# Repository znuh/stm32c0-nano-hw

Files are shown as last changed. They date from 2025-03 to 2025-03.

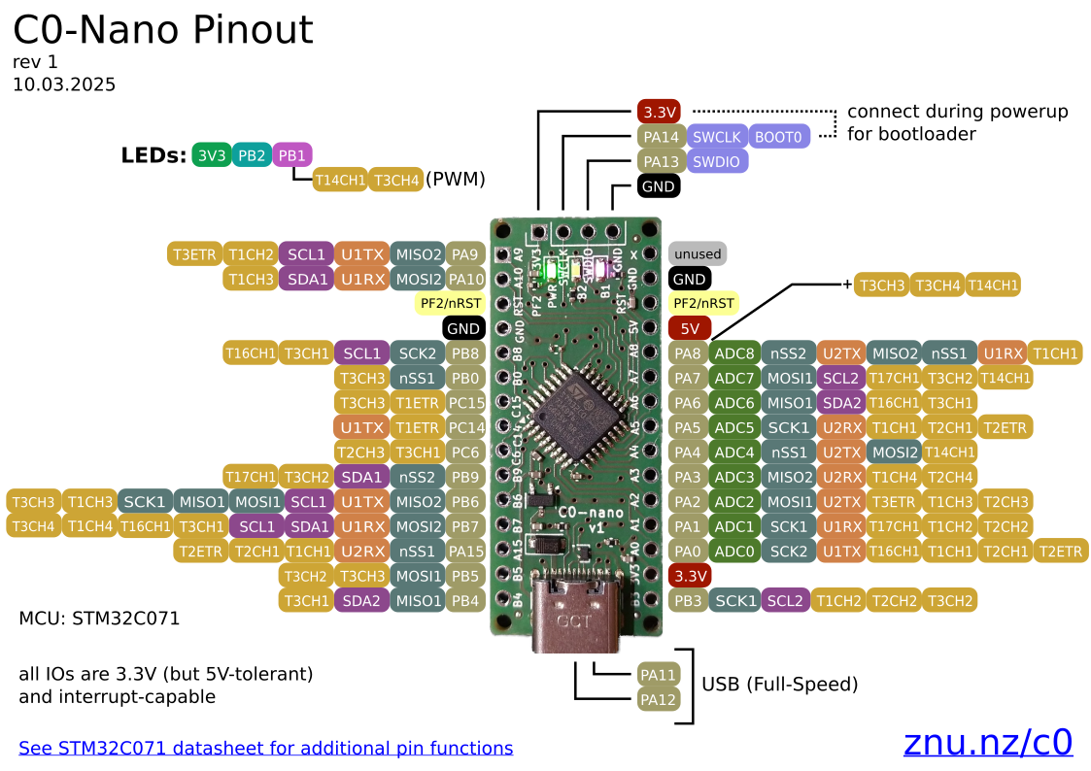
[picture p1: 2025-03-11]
pinouts/pinout.png

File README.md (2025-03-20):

# STM32C0-Nano Hardware Design Files
This is a very simple and cheap STM32C071 board.  

It is largely compatible to ATMega-based "Nano" boards - with 3.3V IOs:  


# Features
* Simple, very low cost (2L, all parts on top of PCB)
* Builtin USB (DFU) bootloader
* Full-speed USB, no crystal needed
(using the Clock Recovery System (CRS))
* 48MHz ARM® Cortex®-M0+ with 24KB SRAM and 128KB Flash memory
* 23+2 GPIOs with 2x SPIs, 2x UARTs, 2x I2C and lots of timer channels
* 9 analog input channels, internal voltage reference
* Fast 2.5MSps 12-bit Analog-to-digital converter (ADC)
* 2x user LEDs (not shared with other GPIOs)

# More Details
see <a href="https://znu.nz/c0">znu.nz/c0</a>

# Demo Firmware
* <a href="https://github.com/znuh/stm32-ACMtest">USB ACM Console + Blinkenlights</a>

# Note
If you build this yourself, you must set the **NBOOT_SEL** Bit in the Flash Option Bytes to **zero** (e.g. via SWD), or you cannot use **BOOT0** to invoke the bootloader during powerup.

# License
Designed by Benedikt Heinz &lt;hunz at mailbox.org&gt;

Creative Commons Attribution/Share-Alike, all text above must be included in any redistribution. See license.txt for additional details.

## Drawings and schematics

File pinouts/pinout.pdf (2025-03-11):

### connect during powerup for bootloader

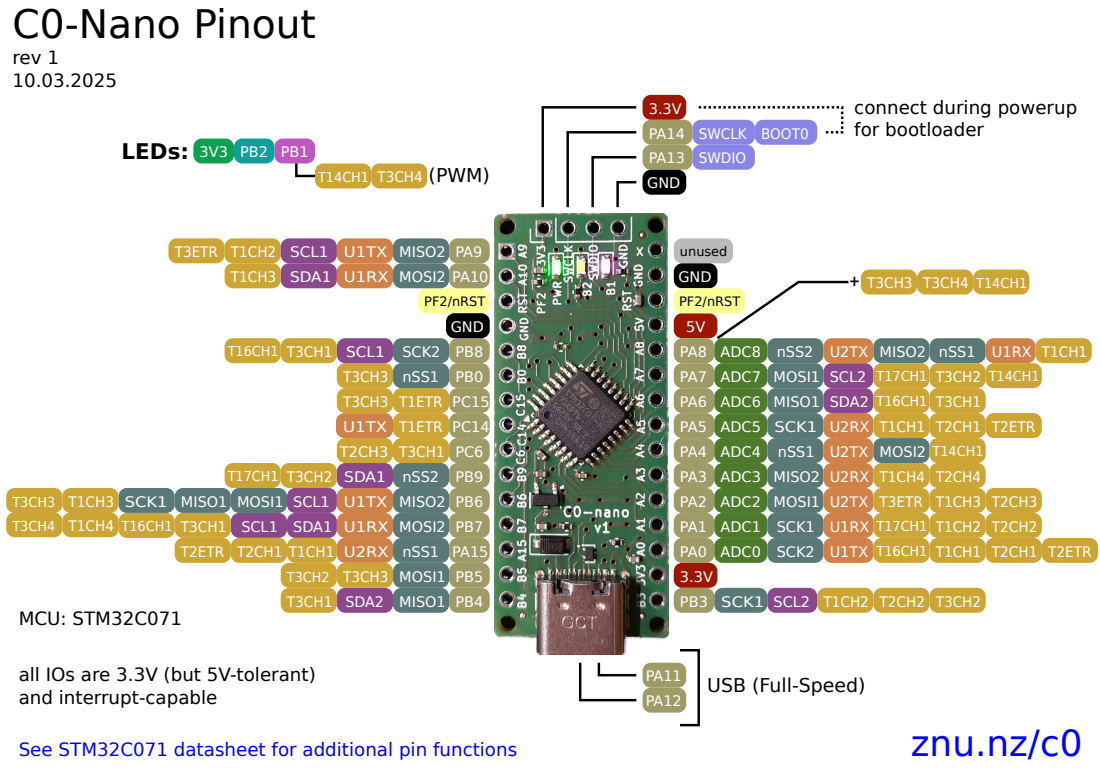
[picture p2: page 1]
GND; PF2/nRST; ADC8 ADC7 ADC6 ADC5 ADC4 ADC3 ADC2 ADC1 ADC0; MISO1; MOSI2; MOSI1; nSS1; SCK2; SCK1; MOSI1 U2TX; MISO2 U2RX; nSS1 U2TX MOSI2; MISO1 SDA2; MOSI1 SCL2; nSS2 U2TX MISO2 nSS1 U1RX; SDA2; U1TX SCL1 SDA1 U1RX; SCK1 MISO1 MOSI1 SCL1; MISO2; SDA1 nSS2; U1TX T1ETR; T3CH3 T1ETR; T3CH3 nSS1; T16CH1 T3CH1 SCL1 SCK2; T1CH2 SCL1; SDA1; T3ETR; T2ETR T2CH1 T1CH1; SCL2 T1CH2 T2CH2 T3CH2; U1TX T16CH1 T1CH1 T2CH1 T2ETR; T3ETR T1CH3 T2CH3; T1CH1 T2CH1 T2ETR; 3.3V PA14 PA13 GND; SWCLK SWDIO; BOOT0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

all IOs are 3.3V (but 5V-tolerant)
and interrupt-capable

See STM32C071 datasheet for additional pin functions (https://www.st.com/resource/en/datasheet/stm32c071kb.pdf)

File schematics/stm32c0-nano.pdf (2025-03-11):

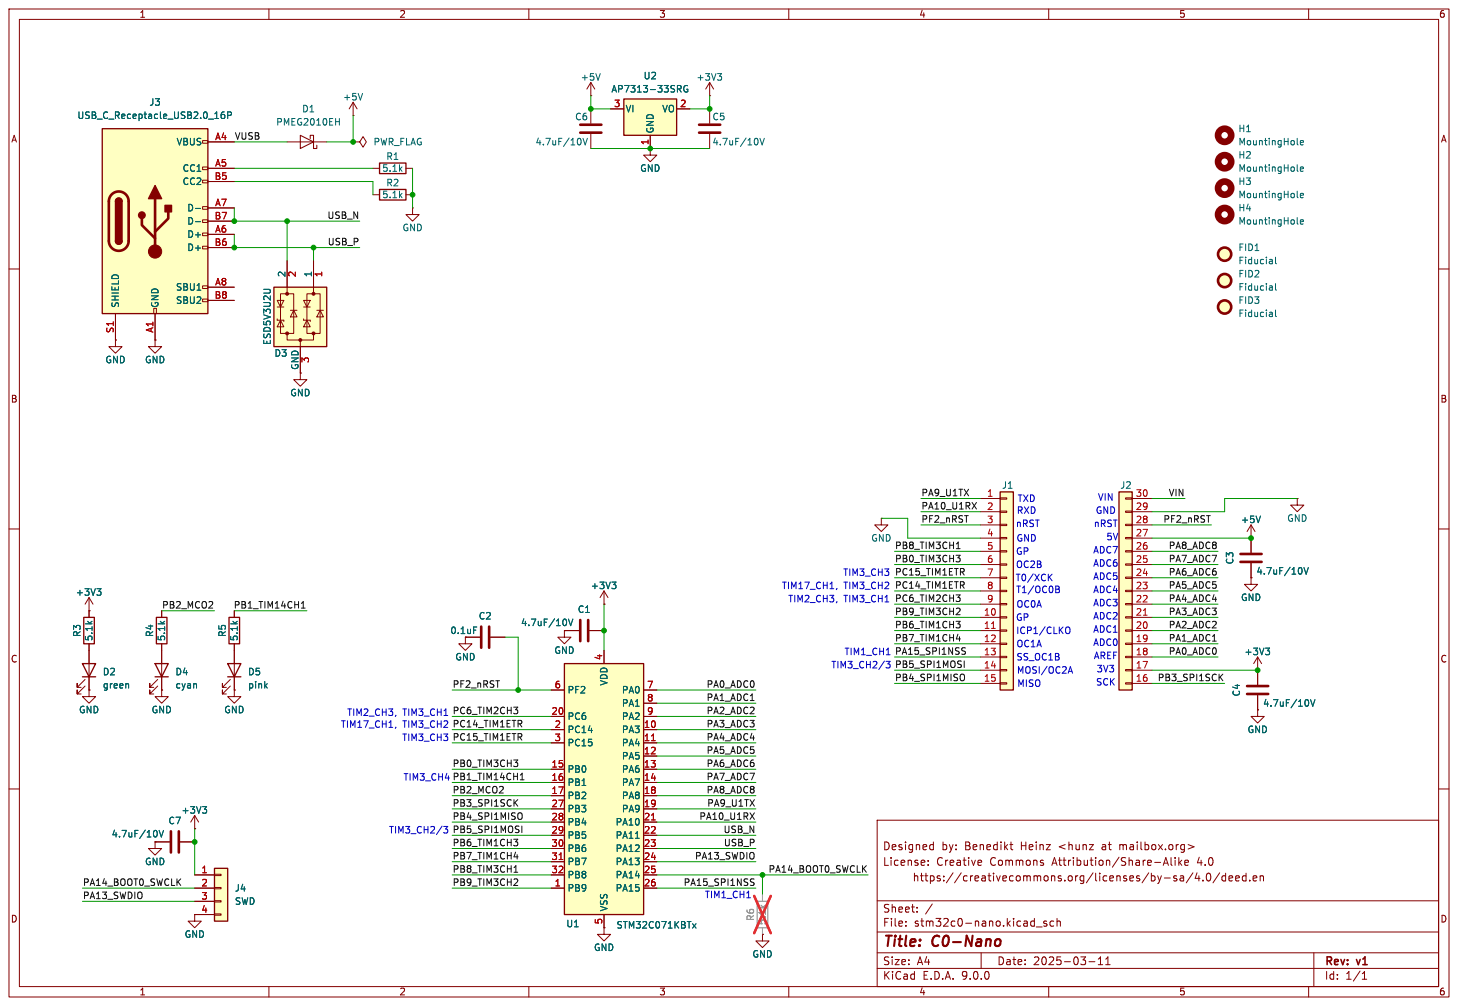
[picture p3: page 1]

File: stm32c0-nano.kicad_sch Sheet: / https://creativecommons.org/licenses/by-sa/4.0/deed.en

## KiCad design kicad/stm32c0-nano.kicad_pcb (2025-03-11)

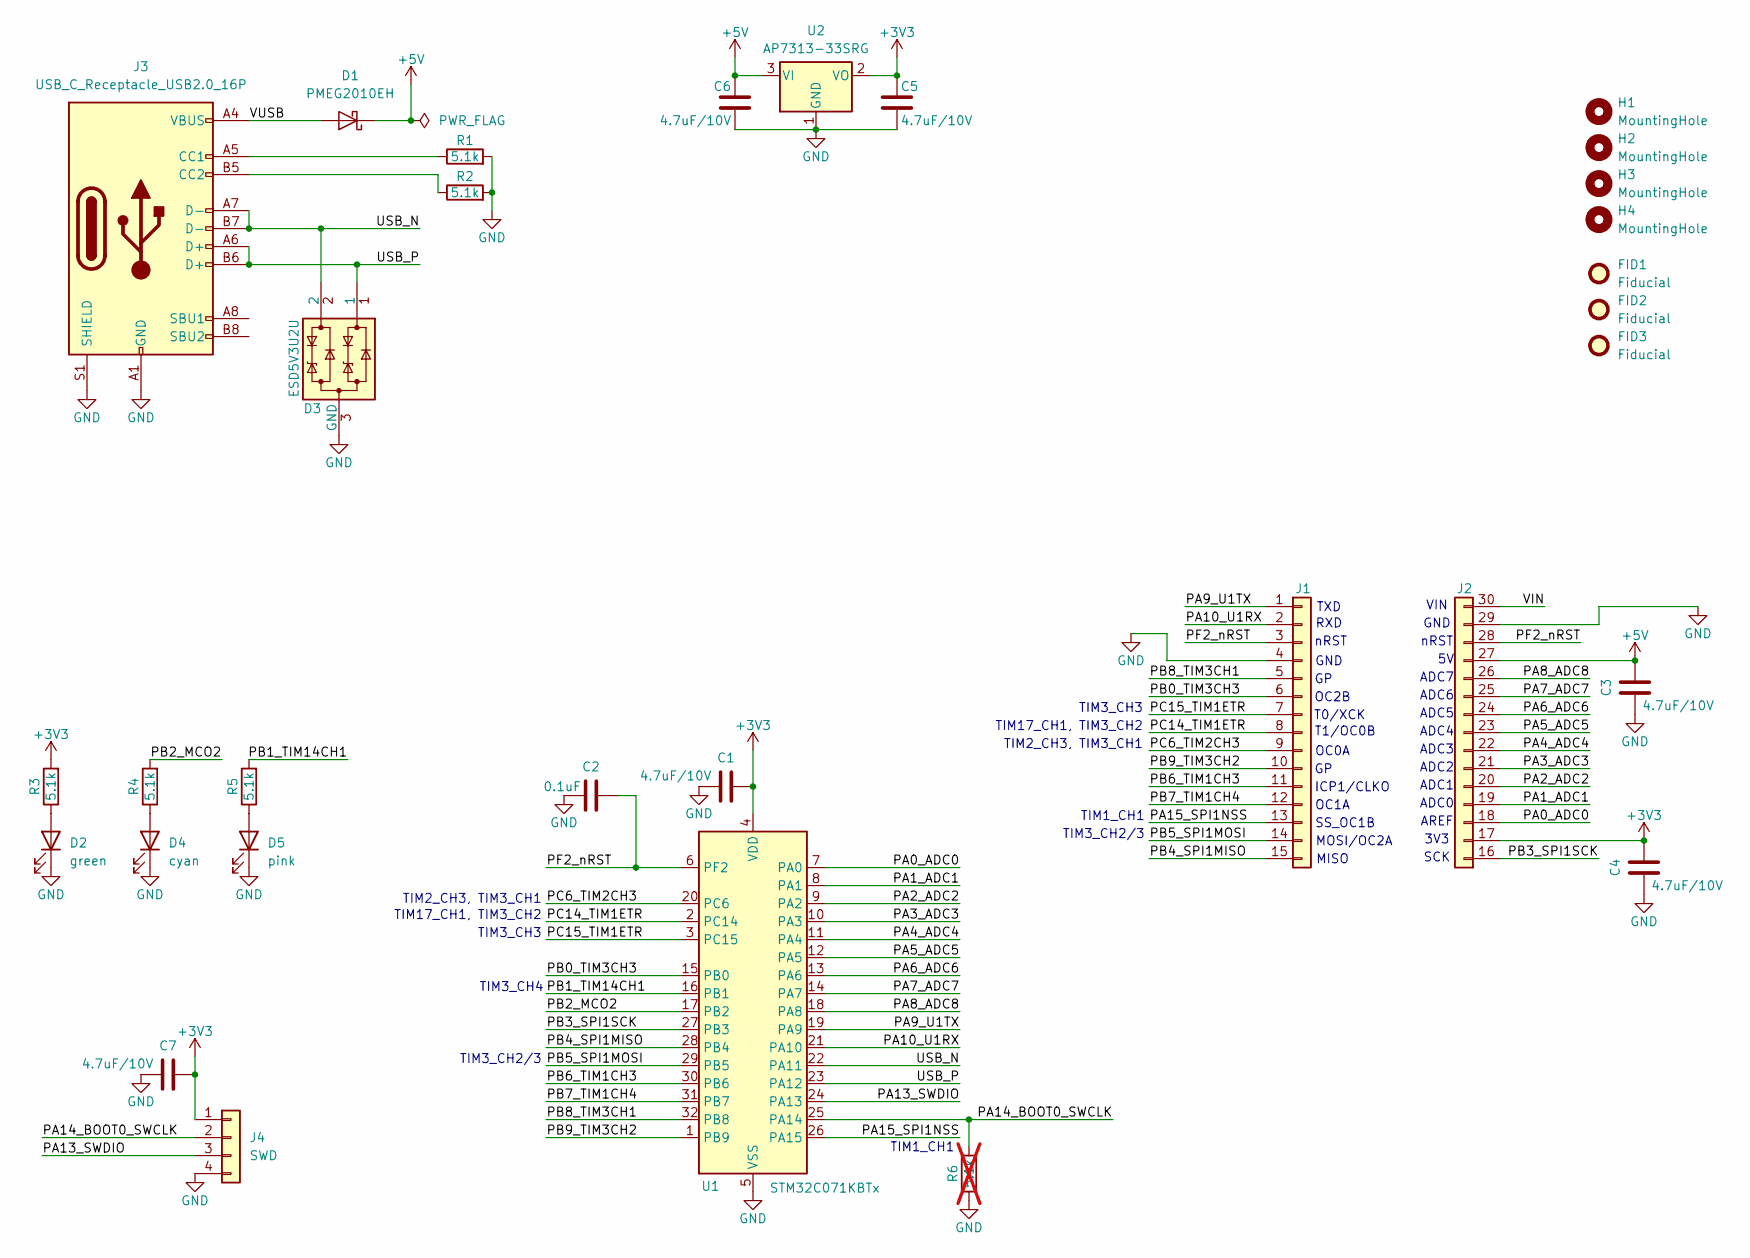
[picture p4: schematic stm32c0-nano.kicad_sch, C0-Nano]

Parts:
C1, C3, C4, C5, C6, C7: 4.7uF/10V; C_0402_1005Metric
C2: 0.1uF; C_0402_1005Metric
D1: PMEG2010EH; D_SOD-123F
D2: green; LED_0603_1608Metric
D3: ESD5V3U2U; Infineon_PG-TSFP-3-1
D4: cyan; LED_0603_1608Metric
D5: pink; LED_0603_1608Metric
FID1, FID2, FID3: Fiducial; Fiducial_0.5mm_Mask1mm
H1, H2, H3, H4: MountingHole; MountingHole_1.65mm
J1: Conn_01x15; PinHeader_1x15_P2.54mm_Vertical
J2: Conn_01x15_16_30; PinHeader_1x15_P2.54mm_Vertical_16_30
J3: USB_C_Receptacle_USB2.0_16P; USB_C_Receptacle_GCT_USB4105-xx-A_16P_TopMnt_Horizontal
J4: SWD; PinHeader_1x04_P2.54mm_Vertical
R1, R2, R3, R4, R5: 5.1k; R_0402_1005Metric
R6: 5.1k; R_0402_1005Metric; not fitted
U1: STM32C071KBTx; LQFP-32_7x7mm_P0.8mm
U2: AP7313-33SRG; SOT-23-3

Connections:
+3V3: C1.2, C4.2, C5.2, C7.2, J2.17, J4.1, R3.2, U1.4 (VDD), U2.2 (VO)
+5V: C3.2, C6.2, D1.1 (K), J2.27, U2.3 (VI)
/PA0_ADC0: J2.18, U1.7 (PA0)
/PA1_ADC1: J2.19, U1.8 (PA1)
/PA2_ADC2: J2.20, U1.9 (PA2)
/PA3_ADC3: J2.21, U1.10 (PA3)
/PA4_ADC4: J2.22, U1.11 (PA4)
/PA5_ADC5: J2.23, U1.12 (PA5)
/PA6_ADC6: J2.24, U1.13 (PA6)
/PA7_ADC7: J2.25, U1.14 (PA7)
/PA8_ADC8: J2.26, U1.18 (PA8)
/PA9_U1TX: J1.1, U1.19 (PA9)
/PA10_U1RX: J1.2, U1.21 (PA10)
/PA13_SWDIO: J4.3, U1.24 (PA13)
/PA14_BOOT0_SWCLK: J4.2, R6.2, U1.25 (PA14)
/PA15_SPI1NSS: J1.13, U1.26 (PA15)
/PB0_TIM3CH3: J1.6, U1.15 (PB0)
/PB1_TIM14CH1: R5.2, U1.16 (PB1)
/PB2_MCO2: R4.2, U1.17 (PB2)
/PB3_SPI1SCK: J2.16, U1.27 (PB3)
/PB4_SPI1MISO: J1.15, U1.28 (PB4)
/PB5_SPI1MOSI: J1.14, U1.29 (PB5)
/PB6_TIM1CH3: J1.11, U1.30 (PB6)
/PB7_TIM1CH4: J1.12, U1.31 (PB7)
/PB8_TIM3CH1: J1.5, U1.32 (PB8)
/PB9_TIM3CH2: J1.10, U1.1 (PB9)
/PC6_TIM2CH3: J1.9, U1.20 (PC6)
/PC14_TIM1ETR: J1.8, U1.2 (PC14)
/PC15_TIM1ETR: J1.7, U1.3 (PC15)
/PF2_nRST: C2.2, J1.3, J2.28, U1.6 (PF2)
/USB_N: D3.2, J3.A7 (D-), J3.B7 (D-), U1.22 (PA11)
/USB_P: D3.1, J3.A6 (D+), J3.B6 (D+), U1.23 (PA12)
/VIN: J2.30
/VUSB: D1.2 (A), J3.A4 (VBUS), J3.A9 (VBUS), J3.B4 (VBUS), J3.B9 (VBUS)
GND: C1.1, C2.1, C3.1, C4.1, C5.1, C6.1, C7.1, D2.1 (K), D3.3 (GND), D4.1 (K), D5.1 (K), J1.4, J2.29, J3.A1 (GND), J3.A12 (GND), J3.B1 (GND), J3.B12 (GND), J3.S1 (SHIELD), J4.4, R1.2, R2.2, R6.1, U1.5 (VSS), U2.1 (GND)
unnamed: D2.2 (A), R3.1
unnamed: D4.2 (A), R4.1
unnamed: D5.2 (A), R5.1
unnamed: J3.A5 (CC1), R1.1
unnamed: J3.B5 (CC2), R2.1

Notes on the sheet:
TIM2_CH3, TIM3_CH1
RXD
GND
TIM3_CH2/3
OC2B
nRST
OC0A
TIM17_CH1, TIM3_CH2
OC1A
ADC7
3V3
ADC6
ADC4
TIM1_CH1
MISO
ADC3
TIM3_CH3
SS_OC1B
VIN
AREF
ADC1
T1/OC0B
ADC0
T0/XCK
TIM3_CH4
ADC5
SCK
ICP1/CLKO
ADC2
MOSI/OC2A
TXD

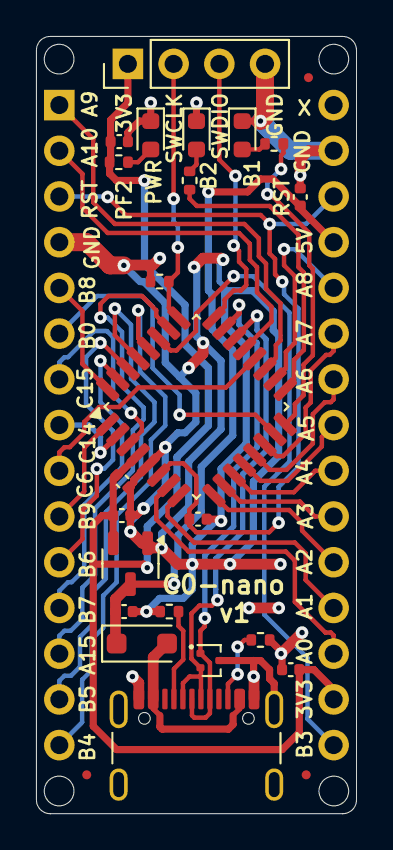
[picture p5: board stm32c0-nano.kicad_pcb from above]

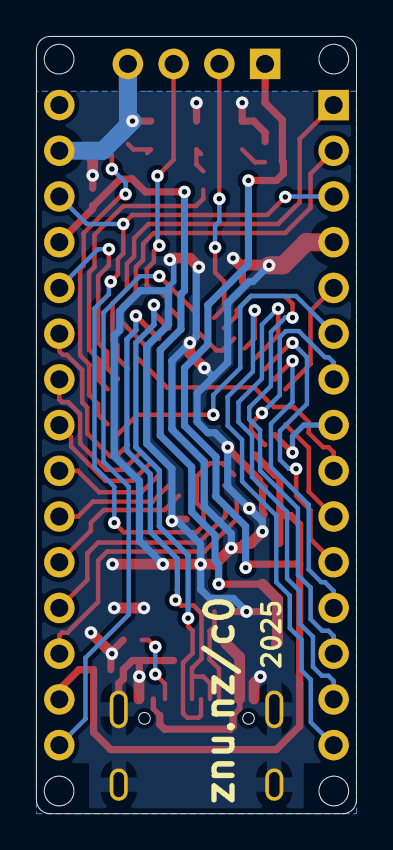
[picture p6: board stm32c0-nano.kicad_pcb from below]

Board: 2 copper layers, 17.8 x 43.2 mm, 31 parts (2 on the bottom side), 39 nets.

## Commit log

2025-03-11 add kicad files
    [stm32c0-nano.kicad_pcb, stm32c0-nano.kicad_sch]
2025-03-11 add schematics, pinouts and ibom

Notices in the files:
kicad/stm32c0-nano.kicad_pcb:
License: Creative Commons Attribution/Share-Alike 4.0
